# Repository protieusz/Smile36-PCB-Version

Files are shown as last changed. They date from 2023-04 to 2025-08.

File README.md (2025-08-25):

# Smile36-PCB-Version

I accept any tips or donations of a cup of coffee to help keep me motivate but you don't have to if you don't want to. Thanks. https://ko-fi.com/protieusz

Update Aug 25, 2025. Got sponsored by PCBWay for PETG print for my new case design of Smile 36 "Chatacabra" from Monster Hunter Wilds.

PCBWay:
For all you 3D printing needs, PCBWay got all types of materials for your printing needs. Ranging from PLA to Resin, https://www.pcbway.com/rapid-prototyping/3d-printing/ for more info. Quality check by PCWay was very good. Their engineer will notify you if you have thin walls in your design and if you want to "risk" printing it. Printed items arrived with quality packing to ensure no damage or scratches during transport. Well worth it. Printing of my PETG for top and bottom case took around 1 day and ship out on the same day via UPS. The item was shipped out on Friday and arrived to my home address on the next Monday. Print quality is very good, rigid and no scratches. Thank you PCBWay!

Smile 36 Chatacabra Pics:
Chatacabra image was borrowed from https://cults3d.com/en/3d-model/jewelry/chatacabra-keychain-mh-wilds-chatacabra-llavero-monster-hunter by NOGARDLABS. Please support & buy his keychain STL files for 3D print. The design was cleaned up very nicely so that it was easily incorporated into my custom keeb design. The design was modified to have the keychain hole removed.








The acrylic paint doesn't go smooth on the PETG material but still looks good.


My PLA 3D Printed Version Using My Bambu A1:




Update: July 9, 2023. Got featured in https://kbd.news/Smile36-2056.html

Update: July 7, 2023

A special thank you to PCBWay (https://www.pcbway.com) for sponsoring my Rev 8 of the Smile 36 GRIN layout keyboard that has every thing working compared to Rev 1 which has the issue of the rows not working.  

Initial order arrived with easily scratch matte black silk screen on all 5 pcbs.  Functionality wise, the pcb work with no issues, continuity check outs. I reported the issues to the representative for my sponsorship and he was kind enough to replace the whole order with a new color pcb of my choice and so I picked purple.  Around 1 week ish, my pcb reprints enter production and was shipped by DHL free of charge to my address.  The results were awesome.  The purple pcbs were bright in color, shiny and the outline cuts were smooth with no sharp edges.  Ordering the pcbs from PCBWay was very easy.  You just specify the pcb dimensions, the pcb thickness, the color you want and leave most of the settings to default.  After you uploaded the gerber files, the status will be in review and an engineer will review your designs and goes into production when it is a passed.  Shipping wise, it has very many options ranging for express to budget shipping.  Prices are in USDs. Here is the direct link for ordering from PCBWay. [(https://www.pcbway.com/project/shareproject/Smile_36_GRIN_Layout_Custom_Keyboard_1b3776b9.html)].  Rev 8 gerber files will be upload to Github soon or you can download from the PCBWay link.

The following are the pictures of my brand new Smile 36 Rev 8 with no more handwiring fixes.

# Disclaimer

This work is a non-commercial fan creation of custom keyboard case and PCB in the shape of SpongeBob & Patrick Star, Chatacabra from the Monster Hunter Wilds & SpongeBob SquarePants series. It is made out of love and respect for the Monster Hunter Wilds & SpongeBob SquarePants series. All rights to Monster Hunter Wilds & SpongeBob SquarePants and related content are owned by Capcom & Nickelodeon and its associated companies. The images, names, storylines and other elements of Chatacabra & SpongeBob SquarePants used in this work are the property of their respective copyright holders. Unauthorized commercial use is strictly prohibited. The Chatacabra & SpongeBob SquarePants and Patrick Star case files will NOT be made public to copyright issues and will be use for private only.

Please print and use the open sourced files at your own risk.

# Pictures

Update: October 8, 2024. Patrick Star Smile 36 case inspired by Patrick from SpongeBob SquarePants.










Some hiccup accident while soldering the mcu. Mcu was soldered on the wrong side. Tried hot plate and hot air and the damn mcu pcb will not come off. All the mcu components came off.
So then I gave up on desoldering the mcu and soldered a new mcu on the correct side and it works. There is hope if you have accidentally "F" up on the mcu. My top and bottom case was created
to accomodate 2 mcu soldered on top and bottom side of the Smile36 PCB. Just make sure you desolder all the components on the mcu PCB and use a yellow tape to prevent any future shorts.














Update: October 4, 2024. Smile 36 case inspired by SpongeBob SquarePants. Featured on [KBDnews](https://kbd.news/Behind-the-scenes-176-2493.html)










Final Smile 36 with no case yet. Note: Case has not been tested yet. As a matter of fact, use everything here at your own risk! No support given.


Bottom side using another spare pcb as bottom plate.


Cross section, no mods yet.


Different angle shots.






Key testing passed.


MCU prep for soldering.


Diode soldering.






Unpackaging pics.







Converted From Handwire To PCB Using EasyEDA

Current Rev 5 pcb has fixed the issues of Rev 1 and also by adding multi layer pads, thru holes for the mcu solder pads, larger pads for easier soldering, added more screw holes in the middle of the pcb so less flexy and stability.  However the Rev 5 pcbs will be untested since I do not have the funds to do a re-print.  Hence the are for public and print, use for at your own risks!  Don't come to me and bitch about it.  It is what it is. No support will be given. Having said that the Rev 5 pcb should work.  Auto routed and no DRC errors. Good luck and have fun.

Added a case STEP file that was used for handwire version. Please modify the STEP file to match the pcb version.

Rev 6 top:
Smile36top2D

Rev 6 bottom:
Smile36bottom2D

Rev 1: My very 1st pcb design, forgot that smd pads only works on 1 layer and not both layers so all my rows are not connected, so had to salvaged it by handwired it to the mcu and it works.

2C95C357-36C3-49F3-93B3-DB3419F9C917_1_105_c

Close up on the handwire fix
2E5C6CA9-7323-4D74-9FE9-750C8D4243E4_1_105_c
710A8FC0-DFCC-4AEC-9DB7-E8EF0D951365_1_105_c

Preview


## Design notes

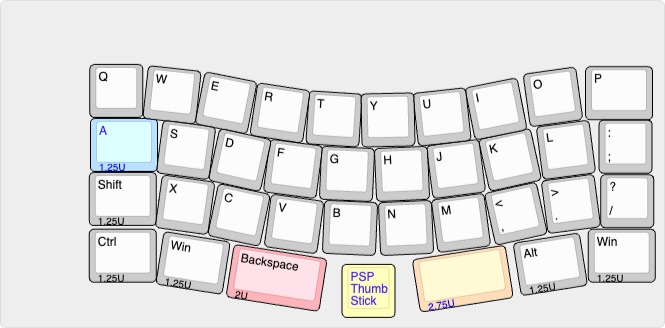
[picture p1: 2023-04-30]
KLE/smilemini.jpg

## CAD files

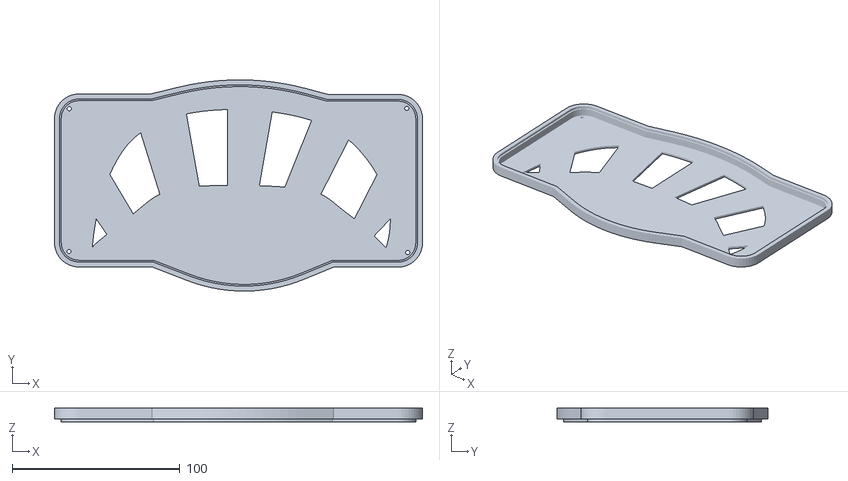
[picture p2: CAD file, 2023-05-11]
PCB Rev 2 Better MCUcutout STLs/Smile36PCBFullCase.stl
219.2 x 125.8 x 8.10

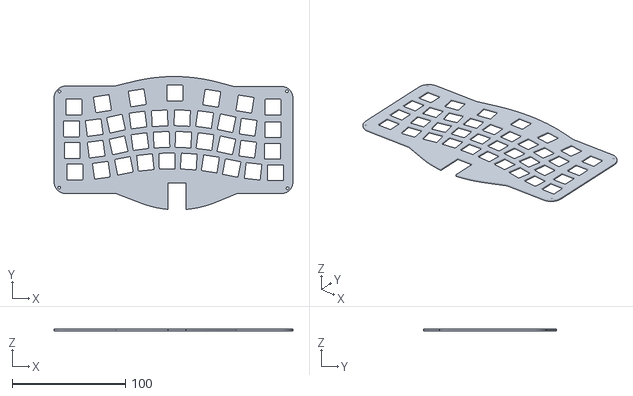
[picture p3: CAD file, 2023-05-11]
PCB Rev 2 Better MCUcutout STLs/Smile36pcbSwitchPlateMcucutout.stl
211.2 x 117.5 x 1.50

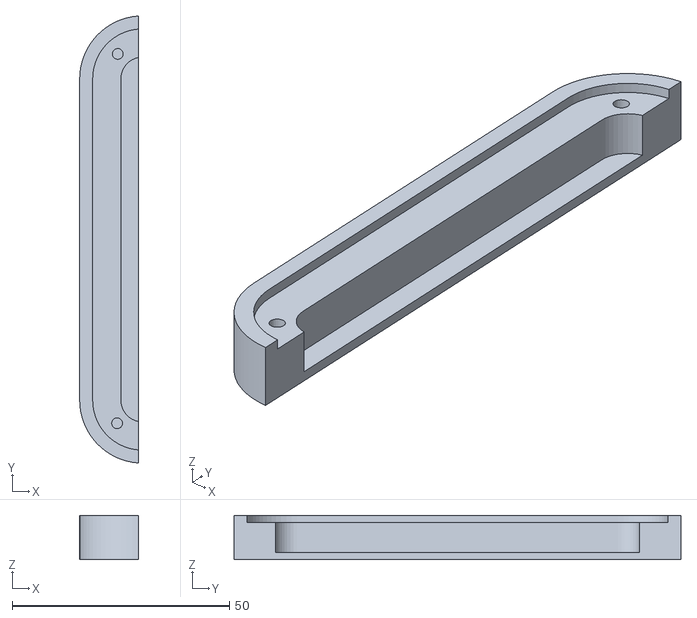
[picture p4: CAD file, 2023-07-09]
Rev8 Case/Smile36PCBcaseEndbitSplit.stl
13.5 x 103.0 x 10.2

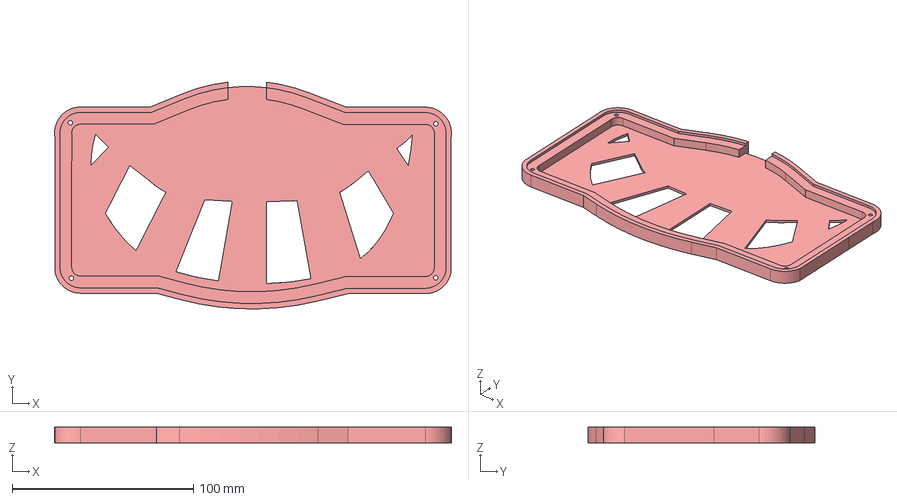
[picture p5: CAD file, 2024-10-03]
Smile36 Virgin Case STEP/Smile Virgin Bottom Case.step
219.2 x 125.2 x 8.60 mm

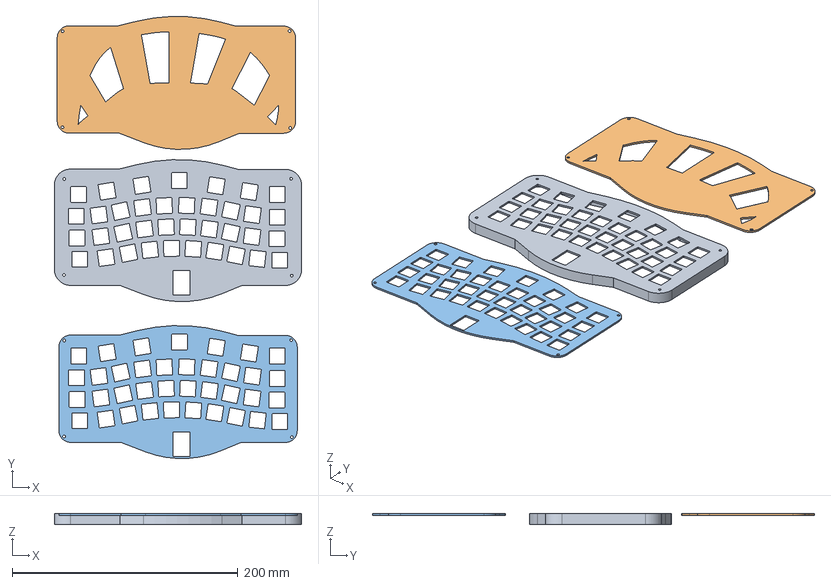
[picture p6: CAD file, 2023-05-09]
STEP file/Smile36PCBBottomSwitchCaseextrudedholes.step
219.2 x 391.6 x 9.60 mm

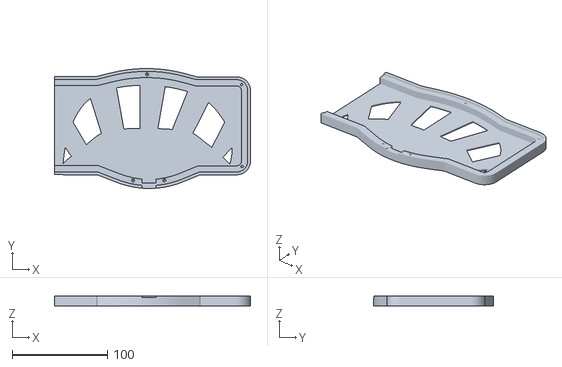
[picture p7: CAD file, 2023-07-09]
Rev8 Case/Smile36PCBBigpiece.stl
205.7 x 125.8 x 10.2

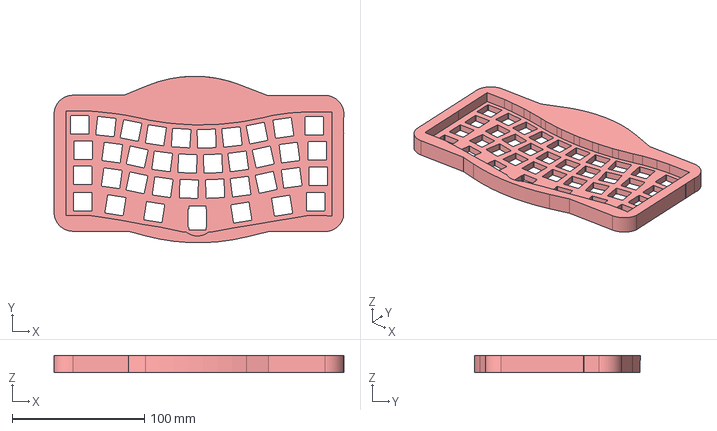
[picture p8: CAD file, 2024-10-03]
Smile36 Virgin Case STEP/Smile36 Virgin Top Case.step
219.2 x 125.8 x 13.0 mm

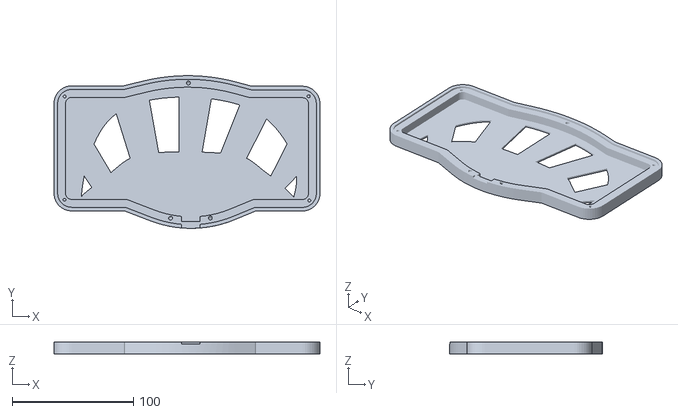
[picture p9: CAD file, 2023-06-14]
Rev8 Case/Smile36CaseTopMountPCB.stl
219.2 x 125.8 x 10.2

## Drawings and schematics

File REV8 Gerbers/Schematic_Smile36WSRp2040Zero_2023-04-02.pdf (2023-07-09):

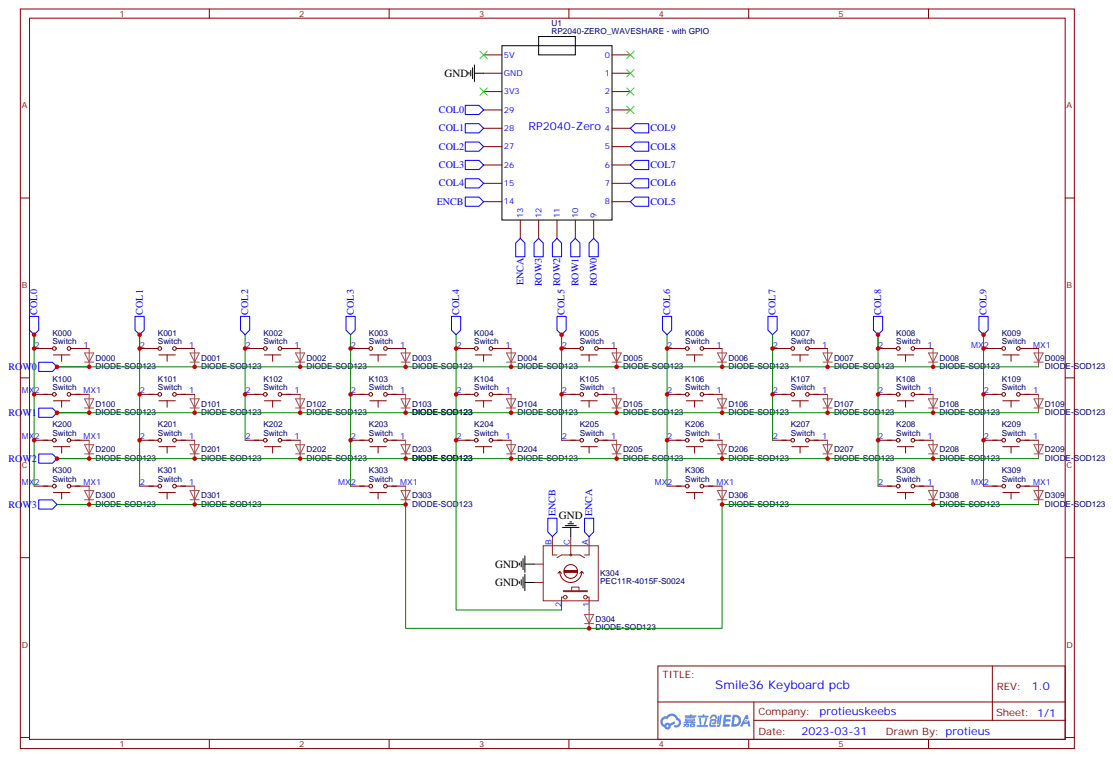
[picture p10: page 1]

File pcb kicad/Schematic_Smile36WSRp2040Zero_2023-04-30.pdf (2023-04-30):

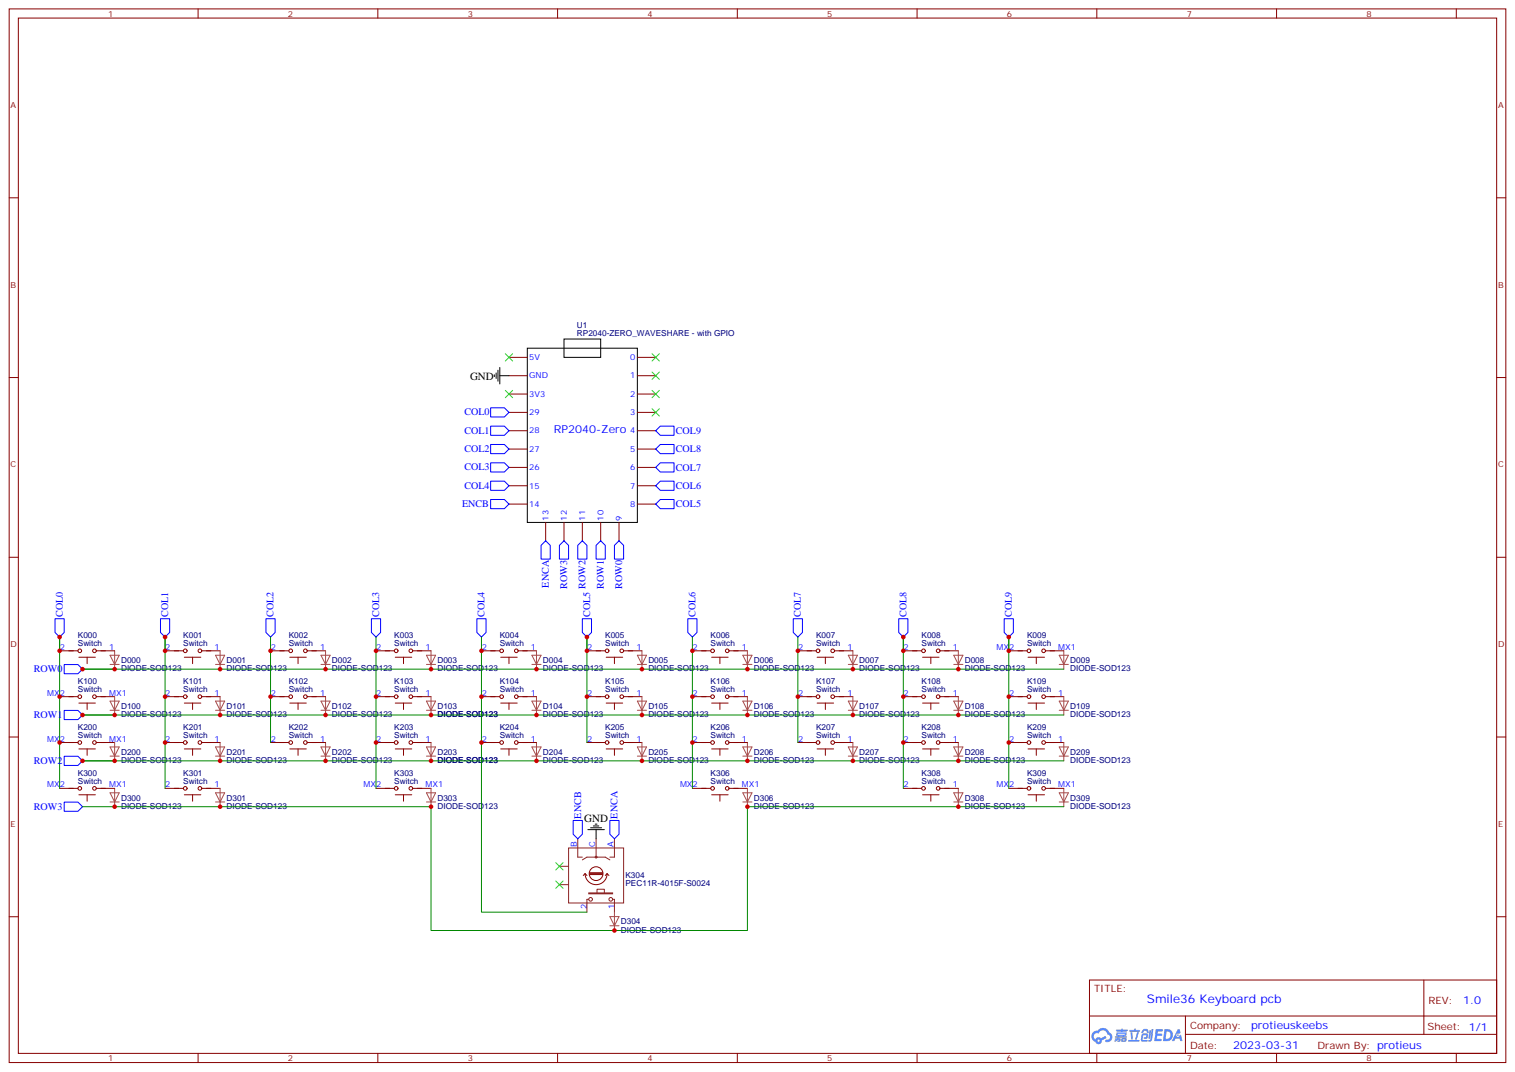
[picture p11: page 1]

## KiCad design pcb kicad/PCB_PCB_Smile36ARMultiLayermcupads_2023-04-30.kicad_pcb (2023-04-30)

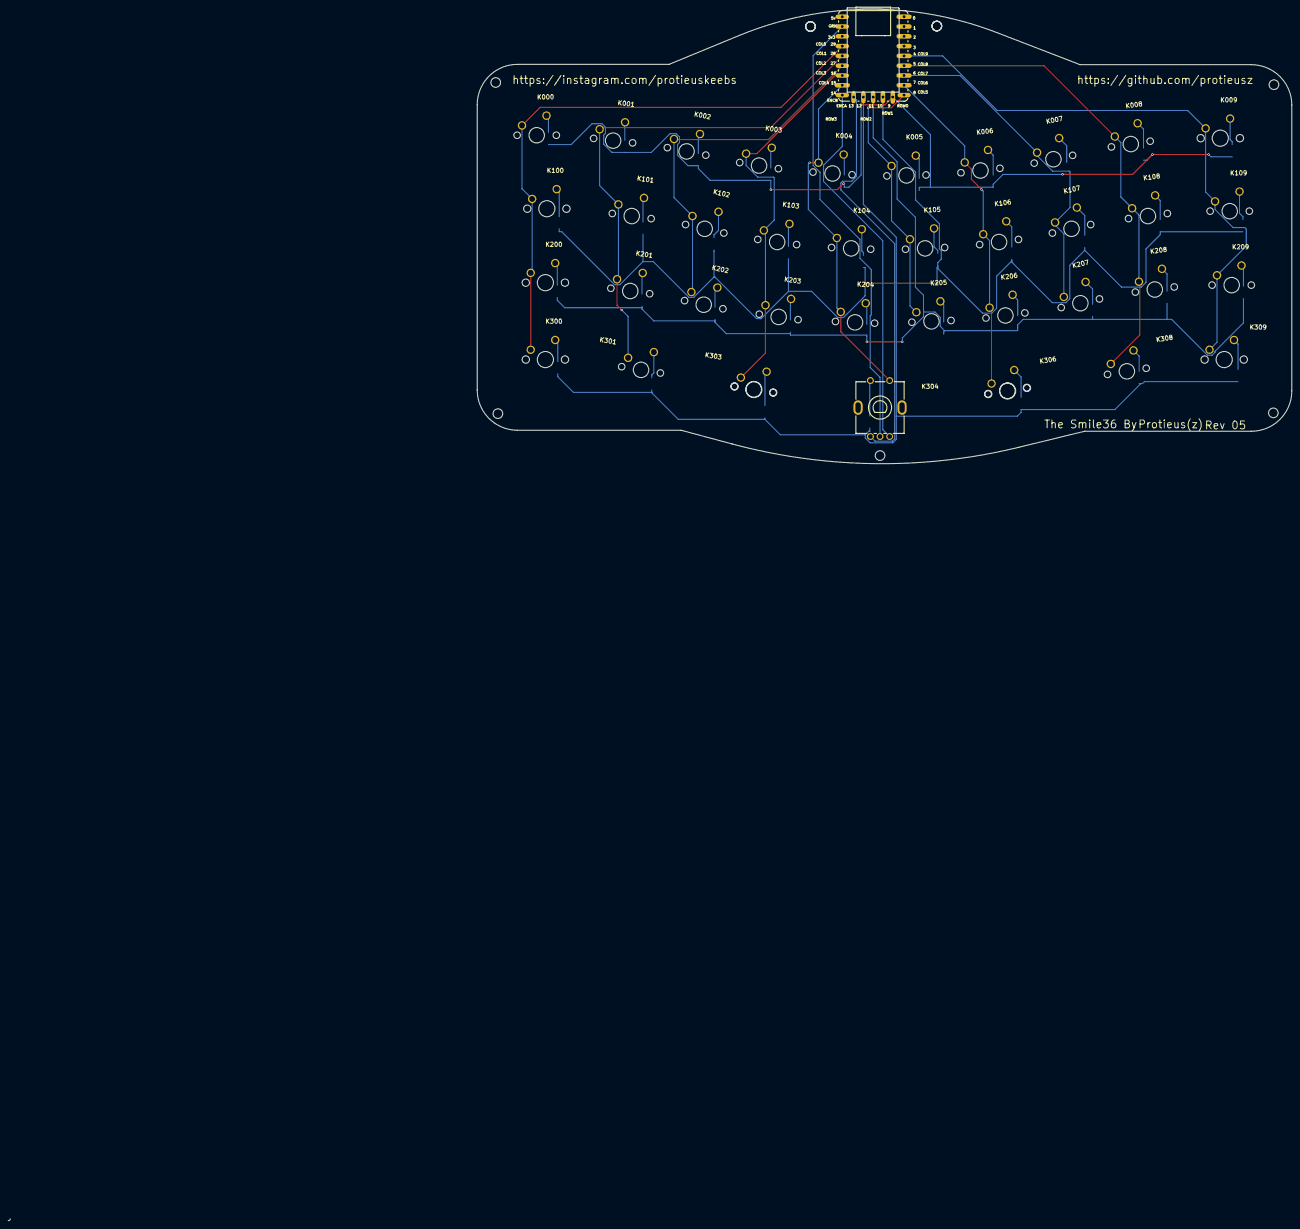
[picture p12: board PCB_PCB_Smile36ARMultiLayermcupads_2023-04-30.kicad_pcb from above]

Board: 2 copper layers, 211.2 x 117.8 mm, 75 parts (0 on the bottom side), 54 nets.

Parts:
D000, D001, D002, D003, D004, D005, D006, D007, D008, D009, D100, D101, D102, D103, D104, D105, D106, D107, D108, D109, D200, D201, D202, D203, D204, D205, D206, D207, D208, D209, D300, D301, D303, D304, D306, D308, D309: DIODE-SOD123
K000, K001, K002, K003, K004, K005, K006, K007, K008, K101, K102, K103, K104, K105, K106, K107, K108, K109, K201, K202, K203, K204, K205, K206, K207, K208, K209, K301, K308: 100; CHERRY_MX_100_MILLMAX
K009, K100, K200, K300, K309: 125; CHERRY_MX_125_MILLMAX
K303, K306: 175; CHERRY_MX_175_MILLMAX
K304: PEC11R-4015F-S0024; SW-TH_PEC11R-4XXXF-SXXXX
U1: RP2040-ZERO_WAVESHARE - with GPIO; RP2040-ZERO_WAVESHARE- W/ GPIO

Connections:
COL0: K000.2, K100.MX2, K200.MX2, K300.MX2, U1.19
COL1: K001.2, K101.2, K201.2, K301.2, U1.18
COL2: K002.2, K102.2, K202.2, U1.17
COL3: K003.2, K103.2, K203.2, K303.MX2, U1.16
COL4: K004.2, K104.2, K204.2, K304.2, U1.15
COL5: K005.2, K105.2, K205.2, U1.8
COL6: K006.2, K106.2, K206.2, K306.MX2, U1.7
COL7: K007.2, K107.2, K207.2, U1.6
COL8: K008.2, K108.2, K208.2, K308.2, U1.5
COL9: K009.MX2, K109.2, K209.2, K309.MX2, U1.4
D000_A: D000.A, K000.1
D003_A: D003.A, K003.1
D005_A: D005.A, K005.1
D007_A: D007.A, K007.1
D009_A: D009.A, K009.MX1
D101_A: D101.A, K101.1
D102_A: D102.A, K102.1
D104_A: D104.A, K104.1
D106_A: D106.A, K106.1
D108_A: D108.A, K108.1
D201_A: D201.A, K201.1
D202_A: D202.A, K202.1
D204_A: D204.A, K204.1
D206_A: D206.A, K206.1
D208_A: D208.A, K208.1
D300_A: D300.A, K300.MX1
D308_A: D308.A, K308.1
D309_A: D309.A, K309.MX1
ENCA: K304.A, U1.13
ENCB: K304.B, U1.14
GND: K304.C, U1.21
K001_1: D001.A, K001.1
K002_1: D002.A, K002.1
K004_1: D004.A, K004.1
K006_1: D006.A, K006.1
K008_1: D008.A, K008.1
K100_MX1: D100.A, K100.MX1
K103_1: D103.A, K103.1
K105_1: D105.A, K105.1
K107_1: D107.A, K107.1
K109_1: D109.A, K109.1
K200_MX1: D200.A, K200.MX1
K203_1: D203.A, K203.1
K205_1: D205.A, K205.1
K207_1: D207.A, K207.1
K209_1: D209.A, K209.1
K301_1: D301.A, K301.1
K303_MX1: D303.A, K303.MX1
K304_1: D304.A, K304.1
K306_MX1: D306.A, K306.MX1
ROW0: D000.C, D001.C, D002.C, D003.C, D004.C, D005.C, D006.C, D007.C, D008.C, D009.C, U1.9
ROW1: D100.C, D101.C, D102.C, D103.C, D104.C, D105.C, D106.C, D107.C, D108.C, D109.C, U1.10
ROW2: D200.C, D201.C, D202.C, D203.C, D204.C, D205.C, D206.C, D207.C, D208.C, D209.C, U1.11
ROW3: D300.C, D301.C, D303.C, D304.C, D306.C, D308.C, D309.C, U1.12

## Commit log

2023-04-03 Update pcb pic
2023-04-27 Upload gerbers rev 5
2023-04-30 Add kicad pcb conversion and schematic
    [PCB_PCB_Smile36ARMultiLayermcupads_2023-04-30.kicad_pcb]
2023-05-03 Update with Rev 6 pcb rendered pics
2023-05-09 Add untested case STEP file
    [Smile36PCBBottomSwitchCaseextrudedholes.step]
2023-05-11 Add untested full case & switch plate pcb
    [Smile36PCBFullCase.stl, Smile36pcbSwitchPlateMcucutout.stl]
2023-06-14 Create top mount pcb case
    [Smile36CaseTopMountPCB.stl]
2023-07-08 Update README.md
    Added PCBWay sponsorship and Rev 8 pics
2023-07-09 Rev8 Gerbers
2023-07-09 Rev 8 Case
    [Smile36CaseTopMountPCB.stl, Smile36PCBBigpiece.stl, Smile36PCBcaseEndbitSplit.stl]
2023-07-09 Update README.md
    Add case warning
2024-10-03 Smile36 Case STEP
    [Smile Virgin Bottom Case.step, Smile36 Virgin Top Case.step]
